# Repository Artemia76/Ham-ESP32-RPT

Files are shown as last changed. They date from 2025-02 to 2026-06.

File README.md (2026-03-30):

<!-- Improved compatibility of back to top link: See: https://github.com/Artemia76/Ham-ESP32-RPT/pull/73 -->

<!--
*** Thanks for checking out the Best-README-Template. If you have a suggestion
*** that would make this better, please fork the repo and create a pull request
*** or simply open an issue with the tag "enhancement".
*** Don't forget to give the project a star!
*** Thanks again! Now go create something AMAZING! :D
-->

<!-- PROJECT SHIELDS -->
<!--
*** I'm using markdown "reference style" links for readability.
*** Reference links are enclosed in brackets [ ] instead of parentheses ( ).
*** See the bottom of this document for the declaration of the reference variables
*** for contributors-url, forks-url, etc. This is an optional, concise syntax you may use.
*** https://www.markdownguide.org/basic-syntax/#reference-style-links
-->
[][contributors-url]
[][forks-url]
[][stars-url]
[][issues-url]
[][license-url]

<!-- PROJECT LOGO -->
<br />
<div align="center">
  <a href="https://github.com/Artemia76/Ham-ESP32-RPT">
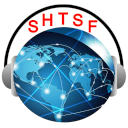
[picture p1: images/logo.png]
    
  </a>

<h3 align="center">HAM-ESP32-RPT</h3>

  <p align="center">
    An ESP32 Based repeater
    <br />
    <a href="https://github.com/Artemia76/Ham-ESP32-RPT"><strong>Explore the docs »</strong></a>
    <br />
    <br />
    <a href="https://github.com/Artemia76/Ham-ESP32-RPT">View Demo</a>
    &middot;
    <a href="https://github.com/Artemia76/Ham-ESP32-RPT/issues/new?labels=bug&template=bug-report---.md">Report Bug</a>
    &middot;
    <a href="https://github.com/Artemia76/Ham-ESP32-RPT/issues/new?labels=enhancement&template=feature-request---.md">Request Feature</a>
  </p>
</div>

<!-- TABLE OF CONTENTS -->
<details>
  <summary>Table of Contents</summary>
  <ol>
    <li>
      <a href="#about-the-project">About The Project</a>
      <ul>
        <li><a href="#built-with">Built With</a></li>
      </ul>
    </li>
    <li>
      <a href="#getting-started">Getting Started</a>
      <ul>
        <li><a href="#prerequisites">Prerequisites</a></li>
        <li><a href="#installation">Installation</a></li>
      </ul>
    </li>
    <li><a href="#usage">Usage</a></li>
    <li><a href="#roadmap">Roadmap</a></li>
    <li><a href="#contributing">Contributing</a></li>
    <li><a href="#license">License</a></li>
    <li><a href="#contact">Contact</a></li>
    <li><a href="#acknowledgments">Acknowledgments</a></li>
  </ol>
</details>

<!-- ABOUT THE PROJECT -->
## About The Project

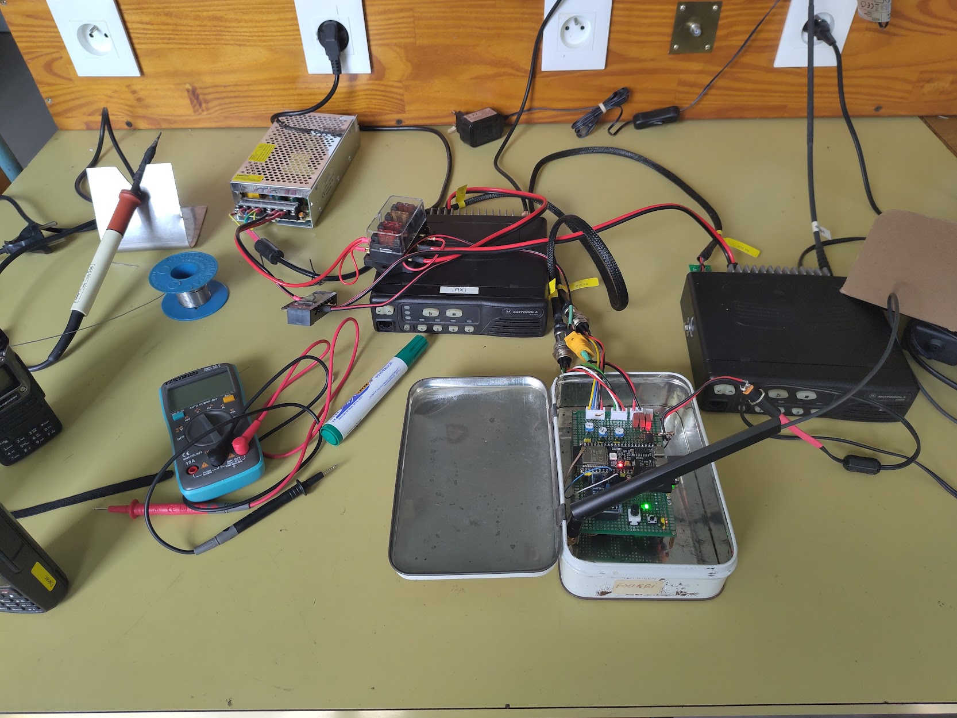
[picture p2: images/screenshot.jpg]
Product Name Screen Shot
[](https://example.com)

This project aim to purpose universal HAM Radio Analog Repeater based on ESP32 MCU.

It based on :
  * ESP32-S3 DevKit Wroom board
  * PmodI2S2 ADC + DAC I2S moodule
  * INA 219 I2C Voltage measurement chip

In addition (optional) we add :
  * Audio monitoring amplifier
  * Test button
  * Red an Green LED state indication

The Repeater feature are :
  * Stream in the RX audio
  * Stream out the TX audio
  * Play start and end announce
  * Detect 1750 Hz tone to engage
  * Read RSSI value by using voltage reading through _ina219 chip
  * TOT ( time out timer) management
  * Web management through WiFi
  * 

<p align="right">(<a href="#readme-top">back to top</a>)</p>

### Built With

* [][PIO-url]

KiCAD for PCB design

Audacity for wav design

<p align="right">(<a href="#readme-top">back to top</a>)</p>

<!-- GETTING STARTED -->
## Getting Started

This is an example of how you may give instructions on setting up your project locally.
To get a local copy up and running follow these simple example steps.

### Prerequisites

**VS Code**
This project need Microsoft [VS Code IDE](https://code.visualstudio.com)

**PIO Arduino**
Search for `pioarduino` on the [Visual Studio Code Marketplace](https://marketplace.visualstudio.com/search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) and follow the documentation [PlatformIO IDE for VSCode](http://docs.platformio.org/page/ide/vscode.html) how to install.

### Installation

_Below is an example of how you can instruct your audience on installing and setting up your app. This template doesn't rely on any external dependencies or services._

1. Clone the repo
   ```sh
   git clone https://github.com/Artemia76/Ham-ESP32-RPT.git
   ```
3. Open folder in VS Code
   
4. Copy and rename the file include/env.hpp.dist to include/env.hpp

5. Enter Wifi Credential has needed in include/env.hpp
   ```
   #define WIFI_SSID "My SSID"
   #define WIFI_PASSWORD "MyVerySecretPassword"
   ```

<p align="right">(<a href="#readme-top">back to top</a>)</p>

<!-- USAGE EXAMPLES -->
## Usage

Use this space to show useful examples of how a project can be used. Additional screenshots, code examples and demos work well in this space. You may also link to more resources.

_For more examples, please refer to the [Documentation](https://example.com)_

<p align="right">(<a href="#readme-top">back to top</a>)</p>

<!-- ROADMAP -->
## Roadmap

- [x] Audio 1750 Hz FFT Detection
- [x] Repeater Sequence
- [X] Web Management
- [X] Permanent Memory
- [ ] PCB Design

See the [open issues](https://github.com/Artemia76/Ham-ESP32-RPT/issues) for a full list of proposed features (and known issues).

<p align="right">(<a href="#readme-top">back to top</a>)</p>

<!-- CONTRIBUTING -->
## Contributing

Contributions are what make the open source community such an amazing place to learn, inspire, and create. Any contributions you make are **greatly appreciated**.

If you have a suggestion that would make this better, please fork the repo and create a pull request. You can also simply open an issue with the tag "enhancement".
Don't forget to give the project a star! Thanks again!

1. Fork the Project
2. Create your Feature Branch (`git checkout -b feature/AmazingFeature`)
3. Commit your Changes (`git commit -m 'Add some AmazingFeature'`)
4. Push to the Branch (`git push origin feature/AmazingFeature`)
5. Open a Pull Request

### Top contributors:

<a href="https://github.com/Artemia76/Ham-ESP32-RPT/graphs/contributors">
  contrib.rocks image
</a>

<p align="right">(<a href="#readme-top">back to top</a>)</p>

<!-- LICENSE -->
## License

Distributed under the Unlicense License. See `LICENSE.txt` for more information.

<p align="right">(<a href="#readme-top">back to top</a>)</p>

<!-- CONTACT -->
## Contact

F4IKZ - [@Neophile76](https://twitter.com/artemia76) - neophile76@gmail.com

Project Link: [https://github.com/Artemia76/Ham-ESP32-RPT](https://github.com/Artemia76/Ham-ESP32-RPT)

<p align="right">(<a href="#readme-top">back to top</a>)</p>

<!-- ACKNOWLEDGMENTS -->
## Acknowledgments

Use this space to list resources you find helpful and would like to give credit to. I've included a few of my favorites to kick things off!

* [Choose an Open Source License](https://choosealicense.com)
* [GitHub Emoji Cheat Sheet](https://www.webpagefx.com/tools/emoji-cheat-sheet)
* [Malven's Flexbox Cheatsheet](https://flexbox.malven.co/)
* [Malven's Grid Cheatsheet](https://grid.malven.co/)
* [Img Shields](https://shields.io)
* [GitHub Pages](https://pages.github.com)
* [Font Awesome](https://fontawesome.com)
* [React Icons](https://react-icons.github.io/react-icons/search)

<p align="right">(<a href="#readme-top">back to top</a>)</p>

<!-- MARKDOWN LINKS & IMAGES -->
<!-- https://www.markdownguide.org/basic-syntax/#reference-style-links -->
[contributors-shield]: https://img.shields.io/github/contributors/othneildrew/Best-README-Template.svg?style=for-the-badge
[contributors-url]: https://github.com/Artemia76/Ham-ESP32-RPT/graphs/contributors
[forks-shield]: https://img.shields.io/github/forks/othneildrew/Best-README-Template.svg?style=for-the-badge
[forks-url]: https://github.com/Artemia76/Ham-ESP32-RPT/network/members
[stars-shield]: https://img.shields.io/github/stars/othneildrew/Best-README-Template.svg?style=for-the-badge
[stars-url]: https://github.com/Artemia76/Ham-ESP32-RPT/stargazers
[issues-shield]: https://img.shields.io/github/issues/othneildrew/Best-README-Template.svg?style=for-the-badge
[issues-url]: https://github.com/Artemia76/Ham-ESP32-RPT/issues
[license-shield]: https://img.shields.io/github/license/othneildrew/Best-README-Template.svg?style=for-the-badge
[license-url]: https://github.com/Artemia76/Ham-ESP32-RPT/blob/master/LICENSE.txt
[product-screenshot]: images/screenshot.jpg
[PIO.js]: https://img.shields.io/badge/pioarduino-000000?style=for-the-badge&logo=pioarduino&logoColor=white
[PIO-url]: https://github.com/pioarduino

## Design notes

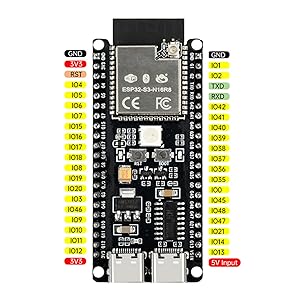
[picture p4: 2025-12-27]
doc/esp32-S3-DevKitC-1-clone-pinout.jpg

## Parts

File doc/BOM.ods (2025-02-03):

Bill of material
Item | Parts or Components | Part Number | Supplier | Unit Cost | Quantity | Cost
1 | ESP32 MCU with Wifi/BT connectivity and I2S capablity | ESP32 ESP32-A1S | AliExpress | 20,00 € | 2 | 40,00 €
3 |  |  |  |  |  | 0,00 €
3 |  |  |  |  |  | 0,00 €
4 |  |  |  |  |  | 0,00 €
4 |  |  |  |  |  | 0,00 €
5 |  |  |  |  |  | 0,00 €
5 |  |  |  |  |  | 0,00 €
6 |  |  |  |  |  | 0,00 €
6 |  |  |  |  |  | 0,00 €
7 |  |  |  |  |  | 0,00 €
7 |  |  |  |  |  | 0,00 €
8 |  |  |  |  |  | 0,00 €
8 |  |  |  |  |  | 0,00 €
9 |  |  |  |  |  | 0,00 €
9 |  |  |  |  |  | 0,00 €
10 |  |  |  |  |  | 0,00 €
10 |  |  |  |  |  | 0,00 €
11 |  |  |  |  |  | 0,00 €
11 |  |  |  |  |  | 0,00 €
12 |  |  |  |  |  | 0,00 €
12 |  |  |  |  |  | 0,00 €
13 |  |  |  |  |  | 0,00 €
13 |  |  |  |  |  | 0,00 €
14 |  |  |  |  |  | 0,00 €
14 |  |  |  |  |  | 0,00 €
15 |  |  |  |  |  | 0,00 €
15 |  |  |  |  |  | 0,00 €
 |  |  |  |  | Total Project : | 40,00 €

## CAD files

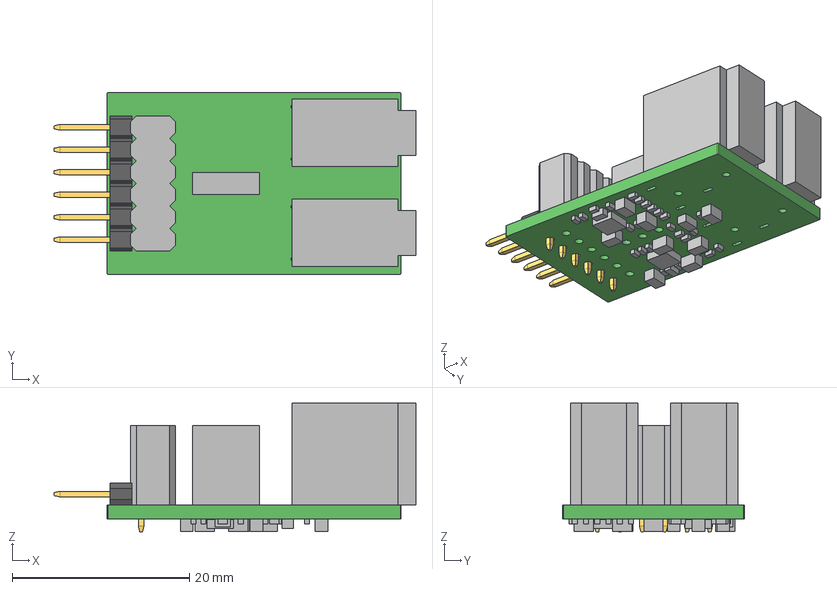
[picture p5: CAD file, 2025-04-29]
doc/PmodI2S2.stp
40.9 x 20.5 x 14.5 mm
Board
Extruded x 42
ConnectorHeader_1x6PMOD_Plastic
ConnectorHeader_1x6PMOD_Pins

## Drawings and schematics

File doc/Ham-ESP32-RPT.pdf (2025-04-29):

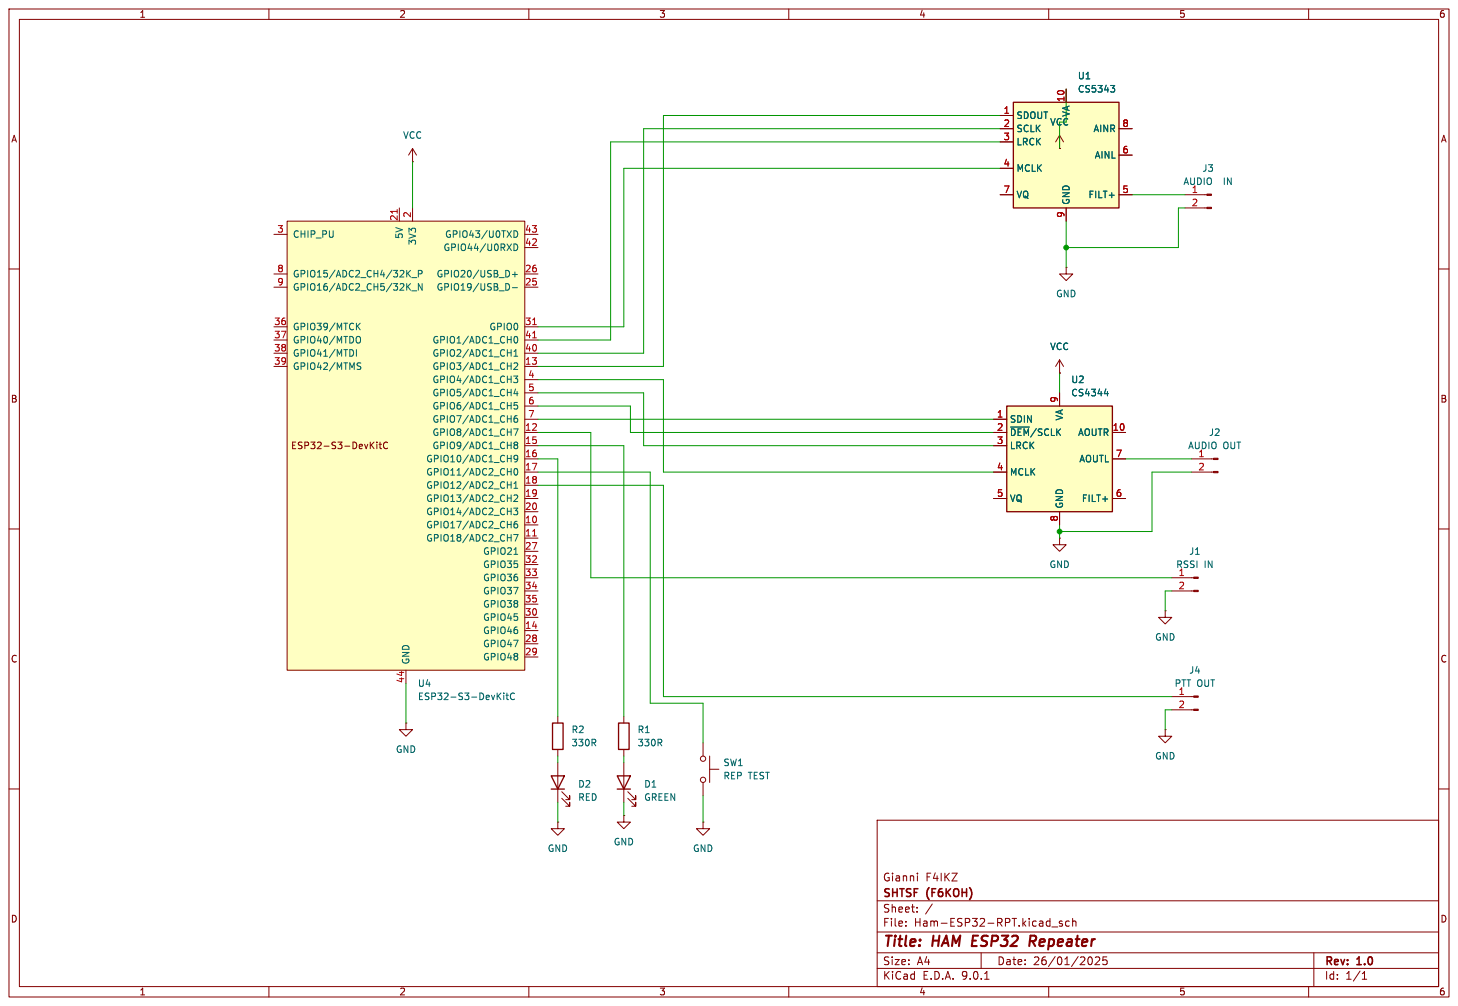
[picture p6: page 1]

J4 PTT OUT GND GND GND

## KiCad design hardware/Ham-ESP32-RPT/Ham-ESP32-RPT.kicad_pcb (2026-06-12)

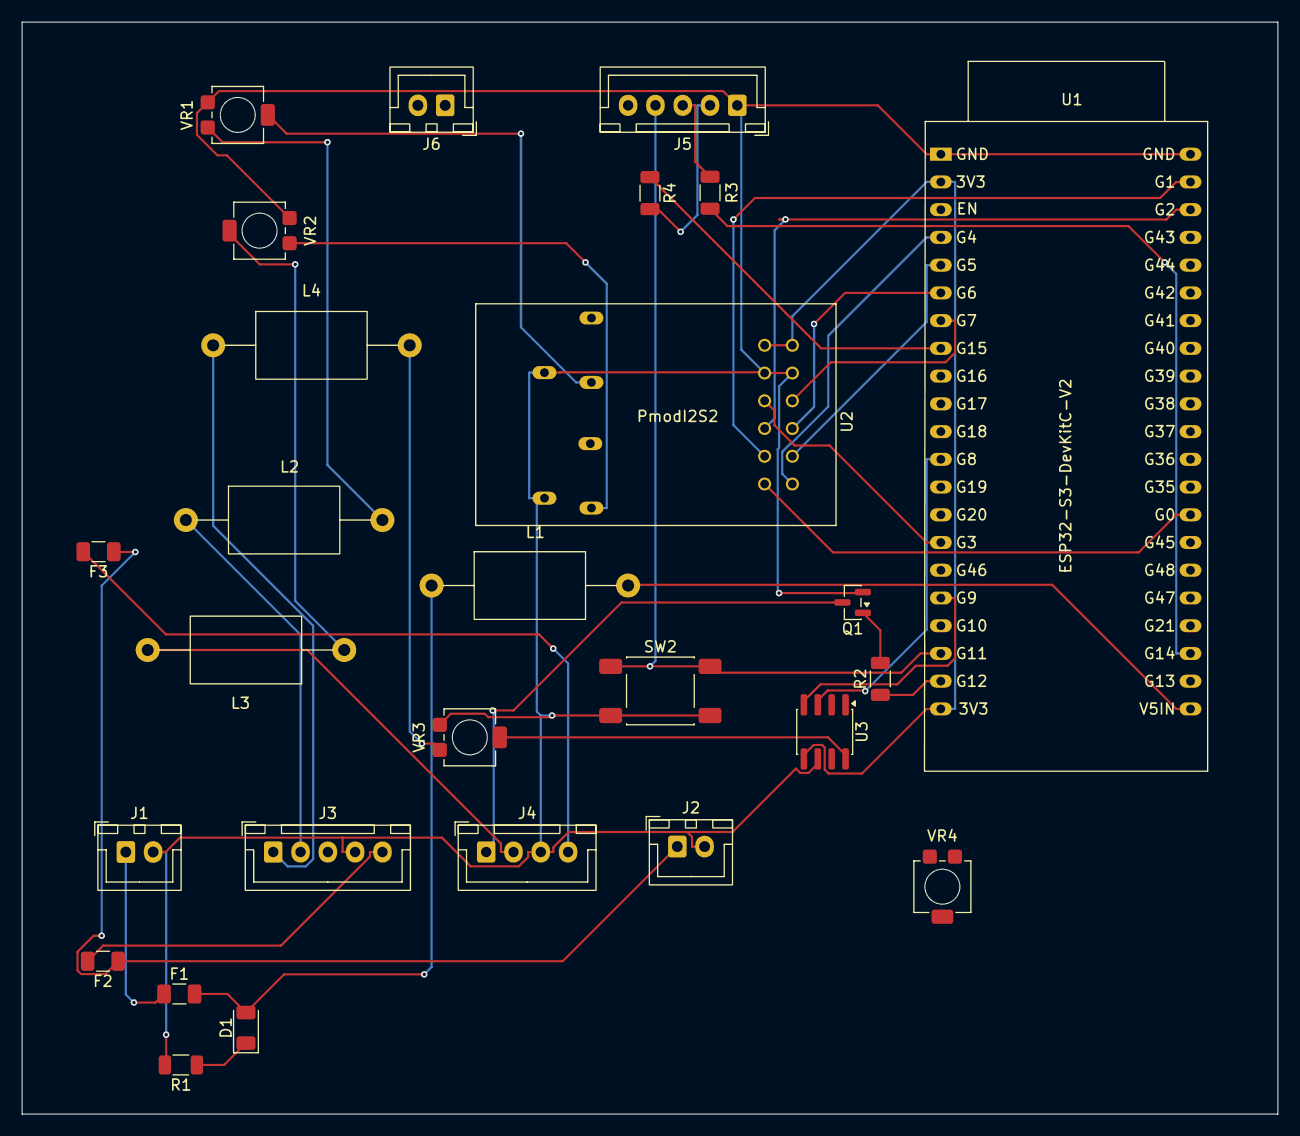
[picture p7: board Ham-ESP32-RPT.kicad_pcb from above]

Board: 2 copper layers, 115.0 x 100.0 mm, 27 parts (0 on the bottom side), 35 nets.

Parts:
D1: BLUE; LED_1206_3216Metric
F1: 2A; Fuse_1206_3216Metric
F2, F3: 4A; Fuse_1206_3216Metric
J1: 5V SUPPLY; JST_XH_B2B-XH-A_1x02_P2.50mm_Vertical
J2: 12V SUPPLY; JST_XH_B2B-XH-A_1x02_P2.50mm_Vertical
J3: RX RADIO; JST_XH_B5B-XH-A_1x05_P2.50mm_Vertical
J4: TX RADIO; JST_XH_B4B-XH-A_1x04_P2.50mm_Vertical
J5: AUX BTN LED; JST_XH_B5B-XH-A_1x05_P2.50mm_Vertical
J6: SPEAKER; JST_XH_B2B-XH-A_1x02_P2.50mm_Vertical
L1, L2, L3, L4: VK200
Q1: MMBT2222A; SOT-23
R1, R3, R4: 330R; R_1206_3216Metric
R2: 3.3K; R_1206_3216Metric
SW2: TEST; SW_Push_1P1T_NO_E-Switch_TL3301NxxxxxG
U1: ESP32-S3-DevKitC-V2
U2: PmodI2S2
U3: INA219AxD; SOIC-8_3.9x4.9mm_P1.27mm
VR1, VR2, VR3, VR4: 10K; Potentiometer_Bourns_3314R-1_Vertical_Hole

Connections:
+3.3V: U1.2 (3V3), U1.21 (3V3), U2.6 (3V3), U2.12 (3V3), U3.5 (VS)
+5V: L1.2, U1.22 (5V)
GND: J1.2, J2.2, J3.4, J4.3, J5.1, Q1.2 (E), R1.2, SW2.2, U1.1 (GND), U1.42 (GND), U2.5 (GND), U2.11 (GND), U2.15 (A_IN_GND), U2.18 (A_OUT_GND), U3.6 (GND), VR1.1, VR2.3, VR3.1, VR4.1
unnamed: D1.2 (A), F1.2, L1.1
unnamed: D1.1 (K), R1.1
unnamed: F1.1, J1.1
unnamed: F2.1, F3.1, J2.1
unnamed: J3.1, L4.1
unnamed: J3.2, L2.1
unnamed: F2.2, J3.5
unnamed: J4.1, Q1.3 (C)
unnamed: J4.2, L3.2
unnamed: F3.2, J4.4
unnamed: J5.2, R4.2
unnamed: J5.3, R3.2
unnamed: J5.4, SW2.1, U1.19 (G11)
unnamed: L2.2, VR1.3
unnamed: L3.1, VR2.2
unnamed: L4.2, VR3.3
unnamed: Q1.1 (B), R2.2
unnamed: U1.29 (G0), U2.1 (ADOUT_MCLK)
unnamed: U1.41 (G1), U2.2 (ADOUT_LRCK)
unnamed: U1.40 (G2), U2.3 (ADOUT_SCLK)
unnamed: U1.15 (G3), U2.4 (ADOUT_SDIN)
unnamed: U1.4 (G4), U2.7 (ADIN_MCLK)
unnamed: U1.5 (G5), U2.8 (ADIN_LRCK)
unnamed: U1.6 (G6), U2.9 (ADIN_SCLK)
unnamed: U1.7 (G7), U2.10 (ADIN_SDOUT)
unnamed: U1.12 (G8), U3.3 (SDA)
unnamed: U1.17 (G9), U3.4 (SCL)
unnamed: R2.1, U1.20 (G12)
unnamed: R3.1, U1.24 (G14)
unnamed: R4.1, U1.8 (G15)
unnamed: U2.13 (A_IN_L), VR1.2
unnamed: U2.16 (A_OUT_L), VR2.1, VR4.3

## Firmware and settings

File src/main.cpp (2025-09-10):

/**
 * @file main.cpp
 * @author Gianni Peschiutta (F4IKZ)
 * @brief HAM-ESP32-RPT
 * @version 0.1
 * @date 2025-02-13
 * 
 * @copyright Copyright (c) 2025
 *
 * 
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
 *    You should have received a copy of the GNU General Public License
 * along with this program.  If not, see <https://www.gnu.org/licenses/>
 */

#include <Arduino.h>
#include "webserver.hpp"
#include "app.hpp"
#include "audio.hpp"
#include "repeater.hpp"

CApp* Application;

/**
 * @brief Initialize MCU
 * 
 */
void setup(void)
{
  delay(5000);
  Application = CApp::Create();
  CRepeater::Create();
  CWebServer::Create();
}

/**
 * @brief Main loop of MCU
 * 
 */
void loop()
{
  Application->Loop();
}

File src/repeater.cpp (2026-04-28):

/**
 * @file repeater.cpp
 * @author Gianni Peschiutta (F4IKZ)
 * @brief HAM-ESP32-RPT
 * @version 0.1
 * @date 2025-02-13
 * 
 * @copyright Copyright (c) 2025
 *
 * 
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
 *    You should have received a copy of the GNU General Public License
 * along with this program.  If not, see <https://www.gnu.org/licenses/>
 */

#include <ArduinoJson.h>

#include "repeater.hpp"

CRepeater::CRepeater() :
    _enabled(true),
    _step(IDLE),
    _lastStep(IDLE),
    _counter(0),
    _lastState(HIGH),
    _currentState(HIGH),
    _CD(false),
    _playingRogerBeep(false),
    _TOT(180),
    _TOT_Counter(0),
    _StartVol(1.0),
    _RBVol(1.0),
    _EndVol(1.0),
    _HalfSecondBlink(false),
    _squelch(6),
    _ina219(0x40),
    _ina219_ok(false),
    _start_message("louise2.wav"),
    _end_message("end.wav"),
    _beep("beep.wav"),
    _t1s(1000,std::bind(&CRepeater::OnTimer1S,this)),
    _t500ms(500,std::bind(&CRepeater::OnTimer500ms,this))

{
  _log = CLog::Create();
  _log->Message("Starting Repeater... ");

  _audio = CAudio::Create();
  _lastCD = _CD;

  //
  // Setting I/O
  //
  pinMode(RX_LED, OUTPUT);
  pinMode(TX_LED, OUTPUT);
  pinMode(ANNONCE_BTN, INPUT_PULLUP);
  pinMode(PTT, OUTPUT);
  
  // Initialize the INA219.
  // By default the initialization will use the largest range (32V, 2A).  However
  // you can call a setCalibration function to change this range (see comments).
  Wire.begin();
  if (! _ina219.begin())
  {
    _log->Message("Failed to find INA219 chip SDA="+ String(SDA) + " SDL=" +String(SCL));
  }
  else
  {
    _ina219_ok=true;
    _RSSI = _rssi2signal.getByVoltage(_ina219.getBusVoltage());
  }

  // Load Config
  _config.begin("repeater",false);
  _enabled = _config.getBool("Enabled","true");
  _squelch = _config.getInt("Squelch",6);
  _TOT = _config.getInt("TOT",180);
  _StartVol = _config.getFloat("StartVol",1.0);
  _RBVol = _config.getFloat("RBVol",1.0);
  _EndVol = _config.getFloat("EndVol",1.0);
  Actions(IDLE);
  _log->Message("OK");
}

/*****************************************************************************/

CRepeater::~CRepeater()
{
  _config.end();
}

/*****************************************************************************/

void CRepeater::OnTimer500ms()
{
  // Animate Green leds
  // If Carriage Detect in IDLE mode , we blink Green Led
  if (_step==IDLE)
  {
    if (_CD && _step==IDLE)
    {
      digitalWrite(RX_LED, _HalfSecondBlink);
    }
    else
    {
      digitalWrite(RX_LED, HIGH);
    }
    digitalWrite(TX_LED, LOW);
  }
  //if Carriage not detected during Repeater active, we blink Red led
  else
  {
    if (!_CD || _step==ANNONCE_FIN)
    {
      digitalWrite(TX_LED, _HalfSecondBlink);
    }
    else
    {
      digitalWrite(TX_LED, HIGH);
    }
    digitalWrite(RX_LED, LOW);
  }
  _HalfSecondBlink = !_HalfSecondBlink;
}

/*****************************************************************************/

void CRepeater::OnTimer1S()
{
  if (!_enabled) return;
  //Grafcet
  switch (_step)
  {
    case IDLE:
    {
      if (_audio->Is1750Detected() && _CD)
      {
        Actions(START_TX);
        _counter = 0;
      }
      break;
    }
    case START_TX:
    {
      //_counter ++;
      if (!_audio->Is1750Detected() && !_CD)
      {
        Actions(ANNONCE_DEB);
      }
      break;
    }
    case ANNONCE_DEB:
    {
      if (!_audio->IsPlaying())
      {
        Actions(REPEATER);
      }
      break;
    }
    case REPEATER:
    {
      if (! _CD) _counter ++;
      else _counter = 0;
      _TOT_Counter++;

      if ((_counter > 10) || (_TOT_Counter >= _TOT))
      {
        Actions(ANNONCE_FIN);
      }
      break;
    }
    case ANNONCE_FIN:
    {
      if (!_audio->IsPlaying())
      {
        Actions(END_TX);
      }
      break;
    }
    case END_TX:
    {
      _counter++;
      if (_counter > 1)
      {
        Actions(IDLE);
      }
    }
  }

  _log->Message("RSSI dBm = " + String(_RSSI.dBm) +
    " RSSI S = " +String(_RSSI.S) +
    " RSSI V = " +String(_RSSI.V) +
    " TOT Timer = " + String(_TOT_Counter) +
    " Squelch = " + String(_squelch),true, CLog::VERBOSE);
}

/*****************************************************************************/

void CRepeater::Actions(const Steps& pStep)
{
  std::lock_guard<std::recursive_mutex> lock(_mutex);
  _counter = 0;
  if (!_enabled) return;
  switch (pStep)
  {
    case IDLE:
    {
      _log->Message("IDLE");
      _audio->SetVolume(0,0.0);
      _audio->SetVolume(2,0.0);
      digitalWrite(PTT,LOW);
      break;
    }
    case START_TX:
    {
      //Wait operator release PTT and 1750 Hz
      _log->Message("Wait CD release to TX");
      break;
    }
    case ANNONCE_DEB:
    {
      _log->Message("Start Message");
      // switch to TX
      digitalWrite(PTT,HIGH);
      //mute input sound still playing welcome
      _audio->SetVolume(0,0.0);
      if ( _audio->IsCTCSSEnabled()) _audio->SetVolume(2,CTCSS_LVL);
      _audio->Play(_start_message, _StartVol);
      break;
    }
    case REPEATER:
    {
      _log->Message("Repeater");
      _lastCD = _CD;
      if (_CD)
        _audio->SetVolume(0,1.0);
      else 
        _audio->SetVolume(0,0.0);
      if (_audio->IsCTCSSEnabled()) _audio->SetVolume(2,CTCSS_LVL);
      _TOT_Counter = 0;
      break;
    }
    case ANNONCE_FIN:
    {
      _log->Message("End Message");
      // Mute repeater
      _audio->SetVolume(0,0.0);
      // If CTCSS is enabled, we enable the osc synth
      if (_audio->IsCTCSSEnabled()) _audio->SetVolume(2,CTCSS_LVL);
      // Play the end message
      _audio->Play(_end_message, _EndVol);
      break;
    }
    case END_TX:
    {
      _log->Message("End TX");
      break;
    }
  }
  _step = pStep;
}

/*****************************************************************************/

void CRepeater::OnUpdate()
{
  std::lock_guard<std::recursive_mutex> lock(_mutex);
  if (_enabled)
  {
    // Manual trig Repeater through button
    _currentState = digitalRead(ANNONCE_BTN);
    if (_lastState == LOW && _currentState == HIGH)
    {
      Actions(START_TX);
    }
    _lastState = _currentState;
    
    // Read RSSI and if threshold, play a K
    if (_ina219_ok)
      _RSSI = _rssi2signal.getByVoltage(_ina219.getBusVoltage());

    // Carriage Detect Management
    _CD = (_RSSI.S >= _squelch);

    if (_CD != _lastCD)
    {
      // only work when repeater active
      if (_step == REPEATER)
      {
        // If lose Carriage , enable repeating else mute the input
        if (!_CD)
        {
          _audio->SetVolume(0,0.0);
          // If last repeating during more than 3 Sec, play RogerBeep
          if ((!_audio->IsPlaying())&&(_TOT_Counter >=3))
          {
              _audio->Play(_beep, _RBVol);
          }
          _TOT_Counter = 0;
        }
        else
        {
          _audio->SetVolume(0,1.0);
        }
      }
      _lastCD = _CD;
    }
  }
  else
  {
    if (_step != IDLE)
    {
      _step = IDLE;
    }
  }
  _t1s.Update();
  _t500ms.Update();

}
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

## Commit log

2025-01-25 amélioration du switch voix/relais
2025-01-26 Add kicad project
    [Ham-ESP32-RPT.kicad_pcb, Ham-ESP32-RPT.kicad_sch]
2025-01-29 Mise à jour de la documentation
    [Ham-ESP32-RPT.kicad_pcb]
2025-02-02 Add BOM to project
    [BOM.ods, Ham-ESP32-RPT.kicad_sch]
2025-02-03 Mise à jour documents
    [Ham-ESP32-RPT.kicad_pcb, Ham-ESP32-RPT.kicad_sch]
2025-02-03 Change sound announce
    [Ham-ESP32-RPT.kicad_sch]
2025-04-14 Add documentation
    [PmodI2S2.stp]
2025-04-29 doc HAM-ESP32
    [Ham-ESP32-RPT.kicad_sch]
2025-04-29 Add TOT and Led blink to carriage detect
2025-06-10 Correct bug for PTT output
    [Ham-ESP32-RPT.kicad_pcb]
2025-06-13 Update Kicad Schematic
    [Ham-ESP32-RPT.kicad_pcb, Ham-ESP32-RPT.kicad_sch]
2025-06-13 update PCB
    [Ham-ESP32-RPT.kicad_pcb]
2025-06-15 Reduce 1750Hz detection timer
2025-06-15 Add DAC ans ADC documentation
2025-07-15 Relevé d'étalonnage du RSSI
    [RSSI Motorola.xlsx]
2025-07-20 I2C adjustment
2025-09-10 Migrate to ESP32 Core v3
2025-09-10 Correct board type in project
2025-12-01 PCB kicad update
    [Ham-ESP32-RPT.kicad_pcb, Ham-ESP32-RPT.kicad_sch]
2026-02-02 Add Vk200 footprint
    [Ham-ESP32-RPT.kicad_pcb, Ham-ESP32-RPT.kicad_sch]
2026-02-17 Add PmodI2S2 footprint
    [Ham-ESP32-RPT.kicad_pcb, Ham-ESP32-RPT.kicad_sch]
2026-02-28 Improve Timer for millis() overflow
2026-02-28 Update Audio lib and start timer bug solve
2026-03-01 Supression pistes
    [Ham-ESP32-RPT.kicad_pcb, Ham-ESP32-RPT.kicad_sch]
2026-03-01 PCB Update
    [Ham-ESP32-RPT.kicad_pcb]
2026-03-12 Add Button to test and restart
2026-03-12 Repair Service mode bug
    [repeater.cpp]
2026-03-30 Correct button position
2026-03-30 Thread safety fix
2026-04-28 Add Roger Beep Filter
2026-06-12 update PCB diagram
    [Ham-ESP32-RPT.kicad_pcb, Ham-ESP32-RPT.kicad_sch]

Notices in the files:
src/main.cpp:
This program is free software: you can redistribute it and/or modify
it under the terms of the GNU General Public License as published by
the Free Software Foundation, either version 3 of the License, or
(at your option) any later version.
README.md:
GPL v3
